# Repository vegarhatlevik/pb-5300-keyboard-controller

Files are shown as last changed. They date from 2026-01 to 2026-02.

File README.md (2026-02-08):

# pb-5300-keyboard-controller
A controller to connect a keyboard for the Apple Powerbook 5300 to a USB based computer.

The purpose of this project is to enable the reuse of the keyboard in a Powerbook 5300 laptop without the logic board. Specifically, it provides a controller with a USB HID interface that enables connecting it to modern computers.

## Hardware
The project hardware consists of a PCB that is hosting an Arduino Leonardo capable microcontroller board. The board used in the development of this project is the Sparkfun Pro Micro. That board was chosen because it was readily at hand in the component cupboard, but in hindsight it might have been better to go with a microcontroller with a higher number of I/O pins. That would have reduced the need for external chips like the demuxers and the shift registers. An idea for a future improvement would be to reimplement it using a larger PIC microcontroller.

## Firmware
The firmware implements a basic keyboard matrix scan and uses a library for USB HID functionality. The Atmel32u4 microcontroller used in Leonardo class boards has built in USB functionality. The library just makes it easier to deal with USB HID, without getting into the details of USB HID protocols. The choice fell on [NicoHood's HID libary](https://github.com/NicoHood/HID). It is very similar to the built in Keyboard of Arduino development tools, and it was chosen over the Arduino library for the simple reason that it provides handling of a keyboard's LED status without diving deep. An added bonus of the chosen library is that it supports the HID boot protocol, which may help with some BIOS implementations, but it is not the reason why it was chosen.

## Credits

During this project I relied heavily on the [excellent post about keyboard design by Michal Trybus](http://blog.komar.be/how-to-make-a-keyboard-the-matrix/) and I stole the idea of using shift registers for working around limited I/O pin numbers from [mehmedbasic.dk](https://mehmedbasic.dk/post/74hc595-keyboard/).

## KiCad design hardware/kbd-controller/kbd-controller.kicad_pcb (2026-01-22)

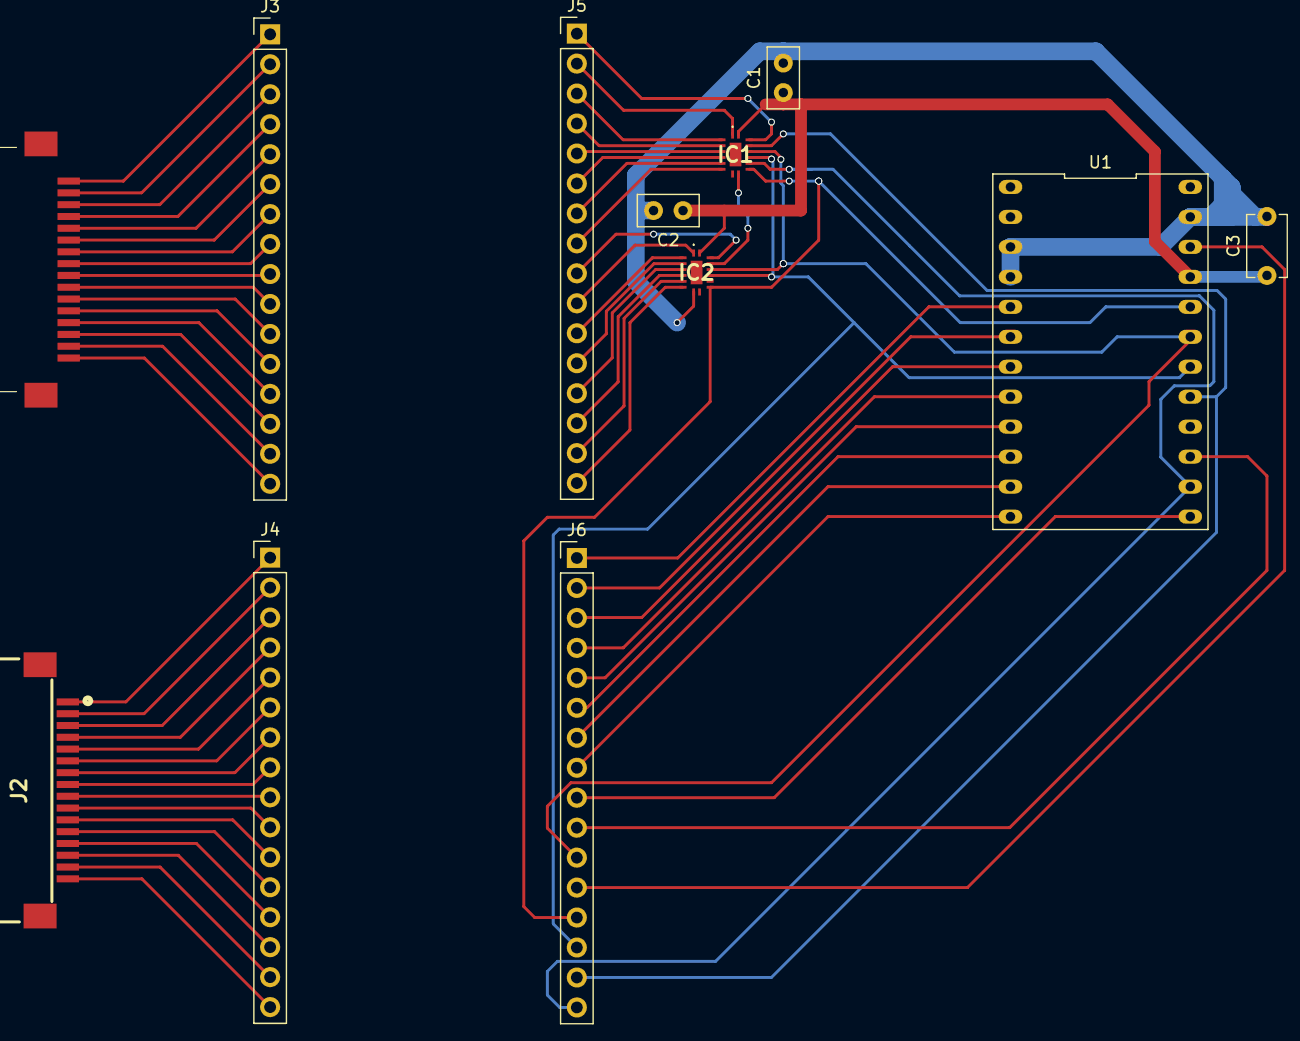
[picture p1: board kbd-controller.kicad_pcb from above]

Board: 2 copper layers, 12 parts (0 on the bottom side), 67 nets.

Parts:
C1, C2: C_Small; C_Disc_D5.0mm_W2.5mm_P2.50mm
C3: C_Polarized_Small; C_Disc_D5.1mm_W3.2mm_P5.00mm
IC1, IC2: SN74AC596BQBR
J1: 52207-1633 MOLEX - Conector FFC/FPC; 52207-1633 MOLEX - Conector FFC_FPC
J2: 52271-1679 MOLEX - Conector FFC/FPC; 52271-1679 MOLEX - Conector FFC_FPC
J3, J4, J5, J6: Conn_01x16_Socket; PinHeader_1x16_P2.54mm_Vertical
U1: Pro Micro Leonardo

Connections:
C1: IC1.15 (QA), J5.1
C2: IC1.1 (QB), J5.2
C3: IC1.2 (QC), J5.3
C4: IC1.3 (QD), J5.4
C5: IC1.4 (QE), J5.5
C6: IC1.5 (QF), J5.6
C7: IC1.6 (QG), J5.7
C8: IC1.7 (QH), J5.8
C9: IC2.15 (QA), J5.9
C10: IC2.1 (QB), J5.10
C11: IC2.2 (QC), J5.11
C12: IC2.3 (QD), J5.12
C13: IC2.4 (QE), J5.13
C14: IC2.5 (QF), J5.14
C15: IC2.6 (QG), J5.15
C16: IC2.7 (QH), J5.16
D10: J6.9, U1.13 (A10/D10)
D14: J6.10, U1.15 (D14)
GND: C1.2, C2.2, C3.2, IC1.8 (GND), IC2.8 (GND), U1.3 (GND), U1.4 (GND), U1.23 (GND)
unnamed: IC1.9 (QH'), IC2.14 (SER)
unnamed: J1.1, J3.1
unnamed: J1.2, J3.2
unnamed: J1.3, J3.3
unnamed: J1.4, J3.4
unnamed: J1.5, J3.5
unnamed: J1.6, J3.6
unnamed: J1.7, J3.7
unnamed: J1.8, J3.8
unnamed: J1.9, J3.9
unnamed: J1.10, J3.10
unnamed: J1.11, J3.11
unnamed: J1.12, J3.12
unnamed: J1.13, J3.13
unnamed: J1.14, J3.14
unnamed: J1.15, J3.15
unnamed: J1.16, J3.16
unnamed: J2.1, J4.1
unnamed: J2.2, J4.2
unnamed: J2.3, J4.3
unnamed: J2.4, J4.4
unnamed: J2.5, J4.5
unnamed: J2.6, J4.6
unnamed: J2.7, J4.7
unnamed: J2.8, J4.8
unnamed: J2.9, J4.9
unnamed: J2.10, J4.10
unnamed: J2.11, J4.11
unnamed: J2.12, J4.12
unnamed: J2.13, J4.13
unnamed: J2.14, J4.14
unnamed: J2.15, J4.15
unnamed: J2.16, J4.16
R1: J6.1, U1.5 (D2)
R2: J6.2, U1.6 (D3)
R3: J6.3, U1.7 (D4/A6)
R4: J6.4, U1.8 (D5)
R5: J6.5, U1.9 (D6/A7)
R6: J6.6, U1.10 (D7)
R7: J6.7, U1.11 (D8/A8)
R8: J6.8, U1.12 (D9/A9)
RCLK: IC1.12 (RCLK), IC2.12 (RCLK), J6.14, U1.18 (A1/D19)
RST: J6.12, U1.22 (RST)
SER: IC1.14 (SER), J6.15, U1.17 (A0/D18)
SRCLK: IC1.11 (SRCLK), IC2.11 (SRCLK), J6.16, U1.14 (D16)
VCC: C1.1, C2.1, C3.1, IC1.16 (VCC), IC2.16 (VCC), U1.21 (VCC)
/OE: IC1.13 (~OE), IC2.13 (~OE), J6.11, U1.19 (A2/D20)
/SRCLR: IC1.10 (~SRCLR), IC2.10 (~SRCLR), J6.13, U1.20 (A3/D21)

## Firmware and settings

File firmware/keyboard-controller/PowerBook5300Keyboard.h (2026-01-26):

class PowerBook5300Keyboard {
private:

  /////////////////////////////////////////////////////////////////////////////
  // Key definitions

  static const uint8_t KEY_PWR = 0xFF; // This should be handled specially, but not yet sure how.
  static const uint8_t KEY_NONE = 0; // Not really needed because it will never be detected.

  static const uint8_t KEY_X = 'x';
  static const uint8_t KEY_C = 'c';
  static const uint8_t KEY_Z = 'z';
  static const uint8_t KEY_V = 'v';
  static const uint8_t KEY_S = 's';
  static const uint8_t KEY_D = 'd';
  static const uint8_t KEY_A = 'a';
  static const uint8_t KEY_F = 'f';

  /////////////////////////////////////////////////////////////////////////////
  // Pin definitions

  static const uint8_t MAX_COLS = 4;
  static const uint8_t MAX_ROWS = 4;

  static const uint8_t ROW_1 = 2;
  static const uint8_t ROW_2 = 3;
  static const uint8_t ROW_3 = 4;
  static const uint8_t ROW_4 = 5;
  /*
  static const uint8_t ROW_5 = 6;
  static const uint8_t ROW_6 = 7;
  static const uint8_t ROW_7 = 8;
  static const uint8_t ROW_8 = 9;

  static const uint8_t _SRCLR = 21;
  static const uint8_t _OE = 20;
  static const uint8_t RCLK = 19;
  static const uint8_t SER = 18;
  static const uint8_t _DETECT = 14;
  static const uint8_t SRCLK = 16;
  */

  static const uint8_t _COL_2 = 6;
  static const uint8_t _COL_3 = 7;
  static const uint8_t _COL_4 = 8;
  static const uint8_t _COL_5 = 9;

  static const uint8_t _CLED = 15; // active low

  const uint8_t outputPins[5] = {_CLED, _COL_2, _COL_3, _COL_4, _COL_5};
  const uint8_t inputPullupPins[4] = {ROW_1, ROW_2, ROW_3, ROW_4};

  /////////////////////////////////////////////////////////////////////////////
  // Layout

  const uint8_t columns[MAX_COLS]={_COL_2, _COL_3, _COL_4, _COL_5};
  const uint8_t rows[MAX_ROWS]={ROW_1, ROW_2, ROW_3, ROW_4};

  uint8_t keyMatrix[MAX_ROWS][MAX_COLS];

  uint8_t previousMatrix[MAX_COLS][MAX_ROWS] = {{1}};
  uint8_t readMatrix[MAX_COLS][MAX_ROWS] = {{1}};

public:
  PowerBook5300Keyboard();
  void init();
  void scan();
};

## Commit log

2026-01-22 Decoupling capacitors
    [kbd-controller.kicad_sch]
2026-01-26 Proof of concept. Implemented just 4 columns and 4 rows due to I/O pin limitation. Will need to be expanded when hardware is complete with shift registers and line decoders.
2026-01-26 Switched to using HID Project library by Nico Hood instead of the standard Keyboard library from Arduino. Added support for Caps Lock led, which is the reason for switching library.
